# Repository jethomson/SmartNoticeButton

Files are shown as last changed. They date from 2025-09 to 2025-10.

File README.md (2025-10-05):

### Introduction
An ESP32 based event scheduler that gives visual and aural notices using LEDs, mp3s saved in flash, and a free TTS service. The case is a big, 3d printed button with a clear cap to show the LEDs. 

<video src="https://private-user-images.githubusercontent.com/2336438/492090742-1041dd4a-3f88-4e7f-9b9a-afa4a4d0a438.mp4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" controls></video>

picture of the web UI for creating events

### Programming ESP32
There are two different ways you can load the code and example files onto the ESP32.

**Method 1**
<br>
[Use a browser that supports Web Serial and program the ESP32 board with this page.](
https://jethomson.github.io/SmartNoticeButton/webflash/flash.html)

**Method 2**
<br>
Download this repository and open it in PlatformIO.
Compile and upload the code.
Click the ant icon on the left hand side, under Platform, click Build Filesystem Image, then click Upload Filesystem Image.

### Hardware
[ESP32 D1 Mini - USB C - Aliexpress](https://www.aliexpress.us/item/3256805791099168.html)
<br>
[ESP32 D1 Mini - USB C - Amazon](https://www.amazon.com/AITRIP-ESP-WROOM-32-Bluetooth-Internet-Development/dp/B0CYC227YG)
<br>
[FCOB LED strip - 5 mm width - Amazon](https://www.amazon.com/dp/B0DBZPL55D)
<br>
[Common WS2812B LED strip - Amazon](https://www.amazon.com/SEZO-Individually-Addressable-Programmable-Non-Waterproof/dp/B097BWJGYK)
<br>
[Max98357 I2S 3W Class D Amplifier - Amazon](https://www.amazon.com/dp/B0B4GK5R1R)
<br>
Normally open momemtary push button with a tall, 6 mm plunger
<br>
Speaker - salvaged from an old desktop (an additional print file of the base without a speaker hole is included so you can add a hole that fits your speaker)
<br>
Three sticky rubber feet for the bottom (not required, but the sound will escape better)

ESP32 to LED strip wiring:
<br>
IO16 -- Green -- DIN 
<br>
 GND -- White -- GND  (use the GND next to IO0)
<br>
 VCC --  Red  --  5V  (use VCC next to IO2)
<br>

ESP32 to Max98357 board wiring:
<br>
IO22 -- Orange -- LRC (wclkPin) 
<br>
IO21 -- Yellow -- BCLK (bclkPin) 
<br>
IO17 -- Green -- DIN (doutPin) 
<br>
 VCC --  Red --  Vin
<br>
 GND -- Black  -- GND
<br>

ESP32 to push button wiring:
<br>
IO26 -- Green -- SW_IN 
<br>
 GND -- Black -- SW_OUT (use the GND next to TXD)

Max98357 board to speaker wiring:
<br>
\+ (plus) hole -- Green -- \+ (plus) pad
<br>
\- (minus) hole -- White -- \- (minus) pad
<br>

photo of smart button disassembled

<br>
Large button cap and plunger hat are printed in a clear PLA.
<br>
Push button support and diffuser are printed in white PLA.
<br>
The base and retaining ring are printed in black PLA.
<br>
<br>
The button cap and diffuser were printed using the following settings in Orca Slicer:
<br>
&nbsp;&nbsp;Quality
<br>
&nbsp;&nbsp;&nbsp;&nbsp;Seam position: Random
<br>
&nbsp;&nbsp;Strength
<br>
&nbsp;&nbsp;&nbsp;&nbsp;Top surface pattern: Archimedean Chords
<br>
&nbsp;&nbsp;&nbsp;&nbsp;Bottom surface pattern: Archimedean Chords
<br>
&nbsp;&nbsp;&nbsp;&nbsp;Sparse infill pattern: Archimedean Chords
<br>
&nbsp;&nbsp;&nbsp;&nbsp;Internal solid infill pattern: Archimedean Chords
<br>
&nbsp;&nbsp;Others
<br>
&nbsp;&nbsp;&nbsp;&nbsp;Reduce infill retraction: unchecked
<br>
Reduce infill retraction prevents stray bits of filament being visible in the infill since the filament is clear.
<br>
A layer height of 0.12 mm was used for the button and 0.2 mm was used for the diffuser.
<br>
<br>
I do not recommend printing the retaining rink with Archimedean Chords. I had trouble with a ring printed this way leaving gaps.
<br>

### Initial Setup
The device can create its own WiFi network or it can connect to your established WiFi network.
You can control the device by connecting directly to its WiFi network, but you will be able to access the device more easily and be able to use the time and date features if you connect it to your WiFi network.

Find the WiFi network named SmartButton and connect to it.
You may get a dialog message like: "The network has no internet access. Stay connected?"
If so, answer Yes. I do not recommend marking the box "[ ] Don't ask again for this network"
In a web browser, open the site smartbutton.local or 192.168.4.1.
Open the Configuration page.
Enter your WiFi network information (SSID and password).
The rest of the fields may be ignored for now.
Click Save.
The device should restart and connect to your WiFi network.
The SmartButton WiFi network should no longer be visible in your list of available networks.
It will appear again if the device no longer has access to your WiFi network (e.g. password changed).

Now any computer or phone on your WiFi network will be able to control the device be visiting smartbutton.local.

**LEDs config**

LEDs number is the count of LEDs in your strip.

LEDs offset is the LED index you want to treat as if it was the start of your LED strip. Since there are physical limitations on where the actual start of the strip can be, the software lets you shift the apparent location of LED 0 to make the visual patterns have a more pleasing orientation.

**VoiceRSS API Key**

[Voice RSS](https://voicerss.org/) offers a free API key for their TTS service with a limit of 350 requests per day. The sign up process is simple and only requires an email address.

**Setting the timezone**

If you want to use UTC time then nothing further is required.

If you would like to use your local time:
<br>
Go to smartbutton.local again and open the Configuration page.
<br>
Delete the information in the IANA Timezone field, and click outside of that field.
With luck your IANA Timezone will be filled in automatically based on the location of your IP address, then a few moments later the POSIX Timezone (has Daylight Saving Time info) will also automatically be filled in. If this information is not correct you can manually set the IANA Timezone, then the POSIX Timezone will automatically update.
Click Save and wait for the device to restart.
Now you should be able to add the time and date to your composites.

### Sound Files and Licences

[chime01.mp3 :: what-friends-are-for-507.mp3](https://notificationsounds.com/wake-up-tones/what-friends-are-for-507)&nbsp;&nbsp;&nbsp;&nbsp;[Creative Commons Attribution license](https://creativecommons.org/licenses/by/4.0/legalcode)<br>
[chime02.mp3 :: simple-notification-1520254.mp3 by Universfield](https://pixabay.com/sound-effects/simple-notification-152054/)&nbsp;&nbsp;&nbsp;&nbsp;[Pixabay license](https://pixabay.com/service/license-summary/)<br>
[chime03.mp3 :: Tannoy chime 01.mp3 by kwahmah_02](https://freesound.org/people/kwahmah_02/sounds/245954/)&nbsp;&nbsp;&nbsp;&nbsp;[Creative Commons Attribution license](https://creativecommons.org/licenses/by/3.0/)<br>

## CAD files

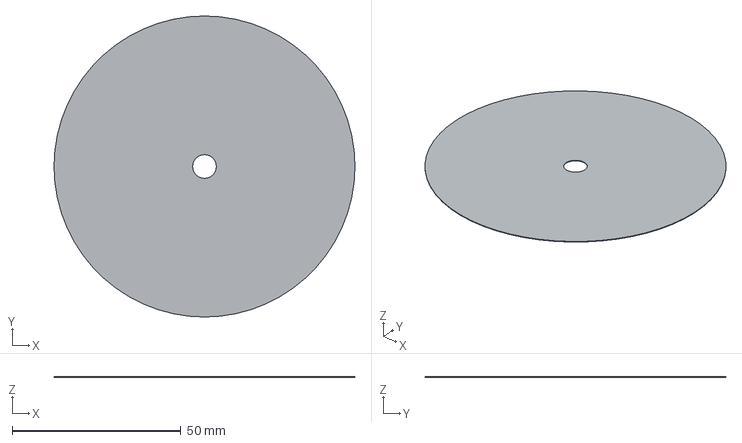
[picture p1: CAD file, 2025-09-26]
3d_printer_files/diffuser.step
89.2 x 89.2 x 0.2 mm

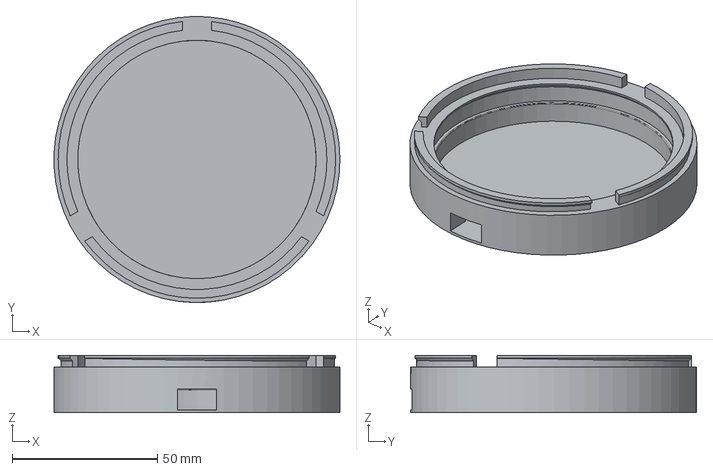
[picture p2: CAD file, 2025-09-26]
3d_printer_files/base_no_speaker_hole.step
98.4 x 98.4 x 19.8 mm

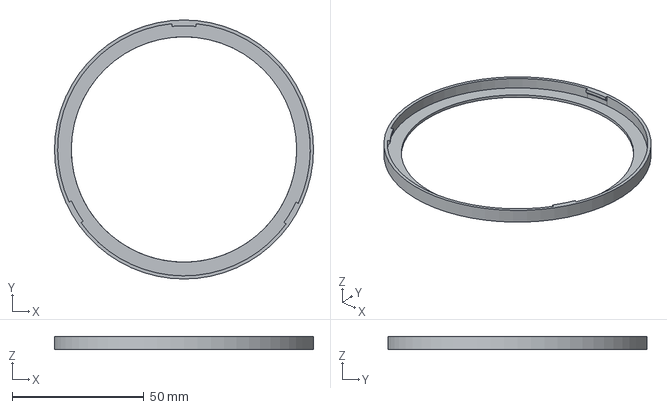
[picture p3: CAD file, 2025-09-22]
3d_printer_files/ring.step
98.4 x 98.4 x 5.00 mm

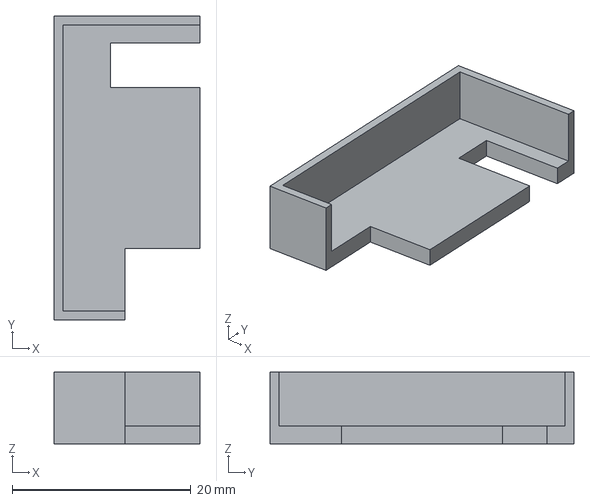
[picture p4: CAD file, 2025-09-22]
3d_printer_files/pushbutton_support.step
16.3 x 34.0 x 8.00 mm

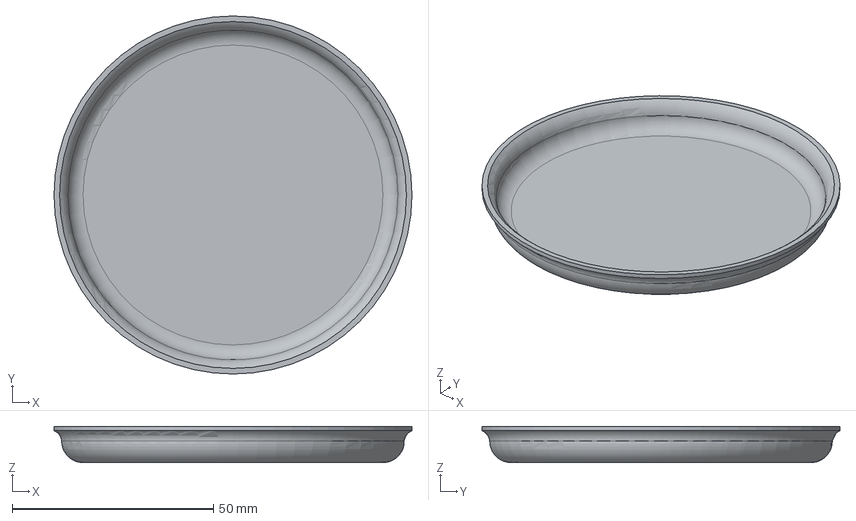
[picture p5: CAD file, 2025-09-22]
3d_printer_files/button_cap.step
89.0 x 89.0 x 9.00 mm

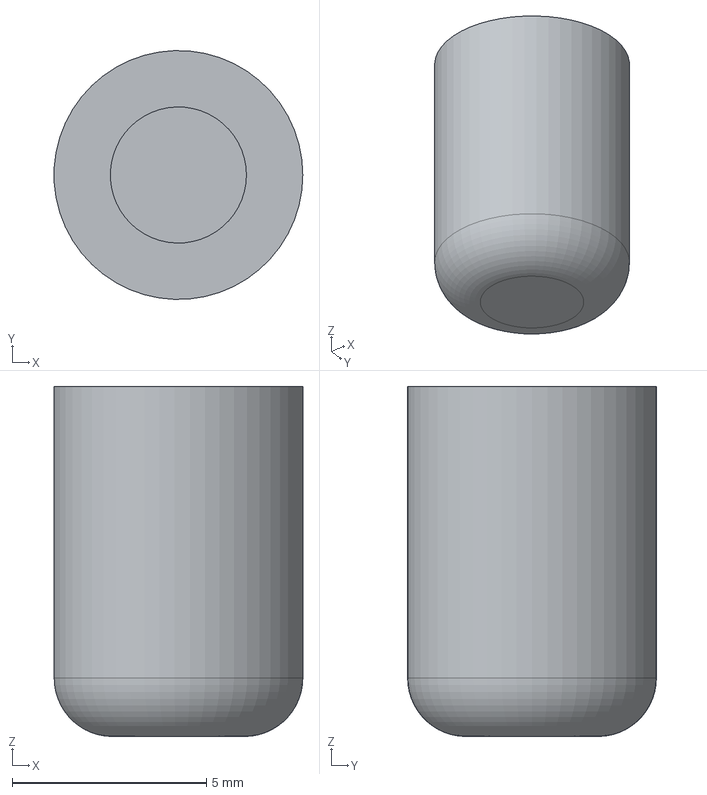
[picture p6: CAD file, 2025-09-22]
3d_printer_files/plunger_hat.step
6.39 x 6.40 x 9.00 mm

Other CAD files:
3d_printer_files/base.step
3d_printer_files/base.stl
3d_printer_files/base_no_speaker_hole.stl
3d_printer_files/button_cap.stl
3d_printer_files/diffuser.stl
3d_printer_files/plunger_hat.stl
3d_printer_files/pushbutton_support.stl
3d_printer_files/ring.stl

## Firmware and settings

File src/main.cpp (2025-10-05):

// events.json specification
// d == description (max 100 chars), f == frequency, sd == start date, st == start time, ed == end date, et == end time, e == exclude, p == pattern, c == color, s == sound, v == voice
// frequency: d == Daily, w == weekly, m == Monthly, y == Yearly
// exclude: is an 8 bit number that stores the sum of the days of the week you wish to skip
//          1 for Sunday, 2 for Monday, 4 for Tuesday, 8 for Wednesday, 16 for Thursday, 32 for Friday, 64 for Saturday
//          for example, if you wish to exclude Saturday and Sunday, then set exclude to 1 + 64 => e:65
//
//{"events":[
//           {"d":"Feed+Fish%2C+Morning","f":"d","sd":[2024,9,25],"st":[8,0,0],"ed":null,"et":null,"e":65,"p":2,"c":"0x00FF0000","s":"chime.mp3","v":"en-ca&v=Clara"},
//           {"d":"Feed+Fish%2C+Afternoon","f":"d","sd":[2024,9,25],"st":[16,0,0],"ed":null,"et":null,"e":65,"p":0,"c":"0x000000FF","s":"chime.mp3","v":"en-ca&v=Clara"}
//          ]
//}
//
// descriptions are percent encoded by the frontend and stored in this format so they can be easily passed to the TTS API.
// the backend trusts that the frontend gives it valid, preformatted data.
// generally, not the best idea, but this is just a personal project and not implement formatting like percent encoding in the backend simplifies the code.


#include <Arduino.h>
#include <FS.h>
//#include "credentials.h" // set const char *wifi_ssid and const char *wifi_password in include/credentials.h
#include <WiFi.h>
#include <WiFiUdp.h>
#include <ESPAsyncWebServer.h>
#include <DNSServer.h>
#include <ESPmDNS.h>
#include <LittleFS.h>
#include <Preferences.h>

#include <FastLED.h>

#include "ArduinoJson-v6.h"
#include <StreamUtils.h>

#include "Button2.h"

#include "AudioFileSourceHTTPStream.h"
#include "AudioFileSourceSPIFFS.h"
#include "AudioFileSourceBuffer.h"
#include "AudioGeneratorMP3.h"
#include "AudioOutputI2S.h"

#include "driver/i2s.h"

#include <vector>

// storage locations for animated matrices and playlists.
// note the pathes are hardcoded in the HTML files, so changing these defines is not enough.
// do not put a / at the end
#define FILE_ROOT "/files"
#define SND_ROOT FILE_ROOT "/snd"
#define USR_ROOT FILE_ROOT "/usr"

#define WIFI_CONNECT_TIMEOUT 10000 // milliseconds
#define SOFT_AP_SSID "SmartButton"
#define MDNS_HOSTNAME "smartbutton"

#define DATA_PIN 16
#define COLOR_ORDER GRB
#define LED_STRIP_VOLTAGE 5
#define LED_STRIP_MILLIAMPS 270
#define HOMOGENIZE_BRIGHTNESS true

#define BUTTON_PIN 26 

#define EVENT_CHECK_INTERVAL 5000 // milliseconds. how frequently checks for events happening now should occur.

#define DESCRIPTION_SIZE 301 // frontend allows up to 100 but with percent encoding the description could become much longer.
#define SOUND_SIZE 101
#define VOICE_SIZE 15 // longest voice string for voicerss: fr-ca&v=Olivia

#define RANDOM_SOUND_MARKER "?????"
#define HTTP_SOUND_PREFIX "http://"

#define SENTINEL_EVENT_ID -1 // event.id is always non-negative, so -1 indicates never seen

#undef DEBUG_CONSOLE
#define DEBUG_CONSOLE Serial
#if defined DEBUG_CONSOLE && !defined DEBUG_PRINTLN
  #define DEBUG_BEGIN(x)     DEBUG_CONSOLE.begin (x)
  #define DEBUG_PRINT(x)     DEBUG_CONSOLE.print (x)
  #define DEBUG_PRINTDEC(x)     DEBUG_PRINT (x, DEC)
  #define DEBUG_PRINTLN(x)  DEBUG_CONSOLE.println (x)
  #define DEBUG_PRINTF(...) DEBUG_CONSOLE.printf(__VA_ARGS__)
  #define DEBUG_FLUSH()     DEBUG_CONSOLE.flush ()
#else
  #define DEBUG_BEGIN(x)
  #define DEBUG_PRINT(x)
  #define DEBUG_PRINTDEC(x)
  #define DEBUG_PRINTLN(x)
  #define DEBUG_PRINTF(...)
  #define DEBUG_FLUSH()
#endif

struct Timezone {
  // TZ is only set at boot, so it is possible for iana_tz and posix_tz to have been updated from default values, but not put into effect yet.
  // therefore we use a separate variable to track if the default timezone is in use instead of trying to do something like compare iana_tz or posix_tz to "" (empty string)
  bool is_default_tz;
  String iana_tz;
  // input from frontend, passed to timezoned.rop.nl for verification and fetching corresponding posix_tz
  // a separate varible is used instead of iana_tz to prevent losing previous data if verify_timezone() fails for some reason (e.g. unverified_iana_tz is an invalid timezone).
  String unverified_iana_tz; 
  String posix_tz;
} tz;

Preferences preferences;

AsyncWebServer web_server(80);
DNSServer dnsServer;
IPAddress IP;
String mdns_host;
bool dns_up = false;

bool restart_needed = false;

// any changes to LEDS_ORIGIN_OFFSET here will be overwritten.
// LEDS_ORIGIN_OFFSET is set in the frontend.
// and DEFAULT_LEDS_ORIGIN_OFFSET is set in platformio.ini.
// since you may be physically limited where you place the first LED when assembling the button
// LEDS_ORIGIN_OFFSET lets you adjust where the apparent origin is. for example, if the first
// LED is physically wired at 1 o'clock you change LEDS_ORIGIN_OFFSET to a value different from
// 0 such that origin *appears* as if it is at 6 o'clock.
uint16_t LEDS_ORIGIN_OFFSET = 0;
// any changes to NUM_LEDS here will be overwritten.
// NUM_LEDS is set in the frontend.
// and DEFAULT_NUM_LEDS is set in platformio.ini.
uint16_t NUM_LEDS = 0;
CRGB* leds;
uint8_t homogenized_brightness = 255;

bool is_audio_message_queued = false;
Button2 button;

struct Event {
  uint16_t id;
  struct tm datetime;
  char frequency;
  struct tm end_datetime;
  char description[DESCRIPTION_SIZE];
  uint8_t exclude;
  uint8_t pattern;
  uint32_t color;
  char sound[SOUND_SIZE];
  bool is_random_sound;
  char voice[VOICE_SIZE];
  time_t timestamp;
};

std::vector<Event> events;
bool events_reload_needed = false;

struct AudioMessage {
  uint32_t id;
  char description[DESCRIPTION_SIZE];
  char sound[SOUND_SIZE];
  char voice[VOICE_SIZE];
  time_t timestamp;
  bool do_long_notify;
};

QueueHandle_t qaudio_messages = xQueueCreate(25, sizeof(struct AudioMessage));

enum Pattern {
  SOLID = 0,
  BREATHE = 1,
  BLINK = 2,
  SPIN = 3,
  TWINKLE = 4
};

enum SpecialColor {
  RAINBOW     = 0x01000000,
  RED_GREEN   = 0x01000001,
  ORANGE_BLUE = 0x01000002,
  YELLOW_PURPLE = 0x01000003
};

std::vector<uint8_t> patterns;
std::vector<uint8_t> special_colors;

uint8_t num_special_colors = 0;

const char* stored_file_list = FILE_ROOT "/file_list.json";
//const char* sound_URLs = FILE_USR "/sound_URLs.json";

String patterns_json;
String special_colors_json;

bool is_wait_over(uint16_t interval);
bool finished_waiting(uint16_t interval);
void homogenize_brightness(void);
void show(void);

void breathing(uint16_t draw_interval);
void blink(uint16_t draw_interval, uint8_t num_blinks, uint8_t num_intervals_off);
//uint16_t forwards(uint16_t index_in);
uint16_t backwards(uint16_t index_in);
void spin(uint16_t draw_interval, uint16_t(*dfp)(uint16_t));
void twinkle(uint16_t draw_interval);
void fill_gradient_RGB_circular(CRGB* leds, CRGB start_color, CRGB end_color);
void fill(uint32_t color);
void visual_reset(void);
void visual_notifier(void);

//void status_callback(void *cbData, int code, const char *string);
void play(AudioFileSource* file);
bool is_valid_mp3_URL(const char* url);
void http_sound(const char* url);
void tell(const char* description, const char* voice, time_t timestamp, bool do_long_notify);
void file_sound(String filename);
void aural_notifier(void* parameter);

bool create_patterns_list(void);
bool create_special_colors_list(void);

void fill_in_datetime(tm* datetime);
tm new_time(uint32_t value, char unit);
tm refresh_datetime(tm datetime, char frequency);
bool is_expired(tm datetime, tm end_datetime);
uint16_t new_id(void);
void set_random_sound(char* sound, size_t sound_len);
bool load_events_file(void);
bool save_file(String fs_path, String json, String& message);
void check_for_recent_events(uint16_t interval);

void single_click_handler(Button2& b);
void long_click_handler(Button2& b);

bool verify_timezone(const String iana_tz);
void espDelay(uint32_t ms);
bool attempt_connect(void);
String get_ip(void);
String get_mdns_addr(void);
//String processor(const String& var);
void wifi_AP(void);
bool wifi_connect(void);
void mdns_setup(void);
bool filterOnNotLocal(AsyncWebServerRequest *request);
void web_server_station_setup(void);
void web_server_ap_setup(void);
void web_server_initiate(void);
time_t time_provider();



// If two functions running close to each other both call is_wait_over()
// the one with the shorter interval will reset the timer such that the
// function with the longer interval will never see its interval has
// elapsed, therefore a second function that does the same thing as
// is_wait_over() has been added. This is only a concern when a pattern
// function and an overlay function are both called at the same time.
// Patterns should use is_wait_over() and overlays should use finished_waiting(). 
bool is_wait_over(uint16_t interval) {
    static uint32_t pm = 0; // previous millis
    if ( (millis() - pm) > interval ) {
        pm = millis();
        return true;
    }
    else {
        return false;
    }
}


bool finished_waiting(uint16_t interval) {
    static uint32_t pm = 0; // previous millis
    if ( (millis() - pm) > interval ) {
        pm = millis();
        return true;
    }
    else {
        return false;
    }
}


// When FastLED's power management functions are used FastLED dynamically adjusts the brightness level to be as high as possible while
// keeping the power draw near the specified level. This can lead to the brightness level of an animation noticeably increasing when
// fewer LEDs are lit and the brightness noticeably dipping when more LEDs are lit or their colors change.
// homogenize_brightness() learns the lowest brightness level of all the animations and uses it across every animation to keep a consistent
// brightness level. This will lead to dimmer animations and power usage almost always a good bit lower than what the FastLED power
// management function was set to aim for. Set the #define for HOMOGENIZE_BRIGHTNESS to false to disable this feature.
void homogenize_brightness(void) {
    uint8_t max_brightness = calculate_max_brightness_for_power_vmA(leds, NUM_LEDS, homogenized_brightness, LED_STRIP_VOLTAGE, LED_STRIP_MILLIAMPS);
    if (max_brightness < homogenized_brightness) {
        homogenized_brightness = max_brightness;
    }
}


void show(void) {
  homogenize_brightness();
  //FastLED.setBrightness(homogenized_brightness);
  FastLED.show();
}


uint16_t idx(uint16_t index_in) {
  return (LEDS_ORIGIN_OFFSET + index_in) % NUM_LEDS;
}


uint8_t br_delta = 0;
void breathing(uint16_t draw_interval) {
  const uint8_t min_brightness = 2;
  if (finished_waiting(draw_interval)) {
    // since FastLED is managing the maximum power delivered use the following function to find the _actual_ maximum brightness allowed for
    // these power consumption settings. setting brightness to a value higher that max_brightness will not actually increase the brightness.
    uint8_t max_brightness = calculate_max_brightness_for_power_vmA(leds, NUM_LEDS, homogenized_brightness, LED_STRIP_VOLTAGE, LED_STRIP_MILLIAMPS);
    uint8_t b = scale8(triwave8(br_delta), max_brightness-min_brightness)+min_brightness;

    FastLED.setBrightness(b);

    br_delta++;
  }
}


uint8_t bl_count = 0;
void blink(uint16_t draw_interval, uint8_t num_blinks, uint8_t num_intervals_off) {
  if (finished_waiting(draw_interval)) {
    if (bl_count < (2*num_blinks)) {
      uint8_t b = (bl_count % 2 == 0) ? homogenized_brightness : 0;
      FastLED.setBrightness(b);
    }
    bl_count++;
    if (bl_count >= 2*num_blinks + num_intervals_off-1) {
      bl_count = 0;
    }
  }
}
 

//uint16_t forwards(uint16_t index_in) {
//  return index_in;
//}


uint16_t backwards(uint16_t index_in) {
  return idx((NUM_LEDS-1)-index_in);
}


void spin(uint16_t draw_interval, uint16_t(*dfp)(uint16_t)) {
  if (finished_waiting(draw_interval)) {
    CRGB color0 = leds[(*dfp)(idx(NUM_LEDS-1))];
    for(uint16_t i = NUM_LEDS-1; i > 0; i--) {
      leds[(*dfp)(idx(i))] = leds[(*dfp)(idx(i-1))];
    }
    leds[(*dfp)(idx(0))] = color0;
  }
}


void twinkle(uint16_t draw_interval) {
  if (finished_waiting(draw_interval)) {
    for(uint16_t i = 0; i < NUM_LEDS; i++) {
      if (random8() < 16) {
        // no real reason to use idx() since these are random indices
        leds[i] = CRGB::White - leds[i];
      }
    }
  }
}


void fill_gradient_RGB_circular(CRGB* leds, CRGB start_color, CRGB end_color) {
  CRGBPalette16 palette;
  for (uint8_t i = 0; i < 16; i++) {
      float ratio = i / 15.0;
      palette[i] = blend(start_color, end_color, ratio*255);
  }
  for (uint16_t i = 0; i < NUM_LEDS; i++) {
    leds[idx(i)] = ColorFromPalette(palette, (i*255)/NUM_LEDS);
  }
}


void fill(uint32_t color) {
  // regular RGB color only uses 24 bits but if color is stored in 32 bits
  // we can utilize the unused upper bits to indicate a color is special
  // colors less than or equal to 0x00FFFFFF are normal RGB colors
  uint8_t color_flag = (color >> 24);
  if (color_flag == 0x00) {
    fill_solid(leds, NUM_LEDS, color);
  }
  else if (color_flag == 0x01) {
    // 0x01------ flag indicates special colors
    if (static_cast<SpecialColor>(color) == RAINBOW) {
      // cannot manipulate the LED indices with idx() for fill_rainbow_circular, but can change the hue at leds[0] which
      // accomplishes the same goal of changing the apparent origin of the LEDs
      const uint16_t hueChange = 65535 / (uint16_t) NUM_LEDS;  // hue change for each LED, * 256 for precision (256 * 256 - 1)
      uint16_t initialhue = (uint8_t)((LEDS_ORIGIN_OFFSET*hueChange) >> 8);  // assign new hue with precise offset (as 8-bit)
      fill_rainbow_circular(leds, NUM_LEDS, initialhue);
    }
    else {
      CRGB color1 = CRGB::Black;
      CRGB color2 = CRGB::Pink;
      if (color == RED_GREEN) {
        color1 = CRGB::Red;
        color2 = CRGB::Green;
      }
      else if (color == ORANGE_BLUE) {
        color1 = CRGB::Orange;
        color2 = CRGB::Blue;
      }
      else if (color == YELLOW_PURPLE) {
        color1 = CRGB::Yellow;
        color2 = CRGB::Purple;
      }
      //fill_gradient_RGB() shows colors more distinctly than fill_gradient()
      //half and half looks better than a gradient since the button cover already diffuses the color
      uint8_t i = 0;
      while(i < NUM_LEDS/2) {
        leds[idx(i)] = color1;
        i++;
      }
      while(i < NUM_LEDS) {
        leds[idx(i)] = color2;
        i++;
      }
    }
  }
  else if (color_flag == 0x02) {
    // 0x02------ flag indicates to fade color across gradient fill
    color = color & 0x00FFFFFF;
    CRGB color_dim = color;
    color_dim.nscale8(20); // lower numbers are closer to black
    fill_gradient_RGB_circular(leds, color, color_dim);
  }
  else {
    // black and pink is used to indicate something went wrong during testing
    fill_gradient_RGB_circular(leds, CRGB::Black, CRGB::Pink);
  }
}


void visual_reset(void) {
  br_delta = 0;
  bl_count = 0;
  finished_waiting(0); // effectively resets timer used for visual effects
  FastLED.clear();
}


// last_id_seen needs to be global so it can be set back to the default by long_click_handler()
// otherwise a reoccurrence of an event with the same id as last_id_seen may not be shown.
int32_t last_id_seen = SENTINEL_EVENT_ID; // event.id is always non-negative, so last_id_seen of -1 indicates never seen
void visual_notifier(void) {
  // NOTE:
  // a design decision was made that the color used by a pattern will not evolve over time.
  // shifting colors are visually appealing, but they are counter productive to serving as a visual indicator
  // for example: one event is blinking blue, and another event is blinking with a shifting color
  //              the shifting color will eventually show blue, so you would have two separate events showing
  //              the same visual indicator.
  const uint32_t SHOW_TIME = 4000; // milliseconds
  static uint16_t i = 0;
  static uint32_t pm = 0;
  static bool refill = true;
  if (!events.empty()) {
    if (i >= events.size()) {
      // if an event was deleted i might be greater than the number of events, so reset it.
      i = 0;
    }
    struct Event event = events[i];
    if (event.timestamp != 0) {
      // if timestamp is 0 then event has not happened since last time notices were cleared
      // so there is no need to show a visual notice for it

      if (event.id != last_id_seen) {
        // by tracking the last_id_seen we can determine if a new notice is about to be shown
        // if it is new notice then reinitialize
        // should only reinitialize once for the SHOW_TIME interval so the pattern can be
        // animated correctly instead of being restarted over and over
        last_id_seen = event.id;
        refill = true;
        visual_reset();
      }

      uint8_t pattern = event.pattern;
      uint8_t randomness = (uint8_t)event.timestamp;
      if (pattern == 255) {
        // 255 indicates a random pattern should be used
        pattern = randomness % patterns.size();
      }
      uint32_t color = event.color;
      if (color == 0xFFFFFFFF) {
        // 0xFFFFFFFF indicates a random color should be used
        bool do_basic = randomness % 3;

        if (do_basic) {
          color = (uint32_t)(CRGB)CHSV((randomness % 255), 255, 255);
          color &= 0x00FFFFFF; // make sure the upper bits are zero to indicate a basic color
        }
        else {
          // do special color
          color = 0x01000000 + (randomness % special_colors.size());
        }
      }

      // for DEBUGGING
      //if (refill) {
      //  DEBUG_PRINT("description: ");
      //  DEBUG_PRINTLN(event.description);
      //  DEBUG_PRINT("pattern: ");
      //  DEBUG_PRINTLN(pattern);

      //  DEBUG_PRINT("color: ");
      //  char hex_color[11];
      //  snprintf(hex_color, sizeof(hex_color), "0x%08lX", color);
      //  DEBUG_PRINTLN(hex_color);
      //}

      switch (pattern) {
        case SOLID:
          FastLED.setBrightness(homogenized_brightness);
          if (refill) {
            refill = false;
            fill(color);
          }
          break;
        case BREATHE:
          if (refill) {
            refill = false;
            fill(color);
          }
          breathing(10);
          break;
        case BLINK:
          //FastLED.setBrightness(homogenized_brightness); // do not use this here. blink changes brightness.
          if (refill) {
            refill = false;
            fill(color);
          }
          blink(200, 3, 10);
          break;
        case SPIN:
          FastLED.setBrightness(homogenized_brightness);
          if (refill) {
            refill = false;
            if (color <= 0x00FFFFFF) {
              // 0x02------ flag indicates to fade color across gradient fill
              // the change in brightness across the fill makes it possible to see the spinning motion
              color += (0x02 << 24);
            }
            fill(color);
          }
          // complete rotation about every 2 seconds independent of the number of LEDs
          spin(2000/NUM_LEDS, &backwards);
          break;
        case TWINKLE:
          FastLED.setBrightness(homogenized_brightness);
          if (is_wait_over(100)) {
            // twinkles should only show momentarily
            // by refilling every time the twinkles from the previous draw disappear
            fill(color);
            twinkle(0);
          }
          break;
        default:
          break;
      }
    }

    // iterate if the event has been shown for SHOW_TIME or event should not be shown
    if ((millis()-pm) > SHOW_TIME || event.timestamp == 0) {
      pm = millis();
      i = (i+1) % events.size();
    }

    show();
  }
  // might not be a bad idea to use else{} and call visual_reset() if the events list is empty to be safe
  // but it would be called every iteration of loop() when events list is empty
}



// Called when there's a warning or error (like a buffer underflow or decode hiccup)
//void StatusCallback(void *cbData, int code, const char *string) {
//  const char *ptr = reinterpret_cast<const char *>(cbData);
//  // Note that the string may be in PROGMEM, so copy it to RAM for printf
//  char s1[64];
//  strncpy_P(s1, string, sizeof(s1));
//  s1[sizeof(s1)-1]=0;
//  DEBUG_PRINTF("STATUS(%s) '%d' = '%s'\n", ptr, code, s1);
//  DEBUG_FLUSH();
//}

//https://github.com/earlephilhower/ESP8266Audio/issues/406

//AudioOutputI2S *audio_out = new AudioOutputI2S();
AudioOutputI2S *audio_out = new AudioOutputI2S(0, 0, 32, 0); // increase DMA buffer. does this help with beginning of sound being cutoff?
AudioGeneratorMP3 *mp3 = new AudioGeneratorMP3();
bool mp3_stop_requested = false;
void play(AudioFileSource* file) {
  AudioFileSourceBuffer *buff;
  buff = new AudioFileSourceBuffer(file, 2048);
  mp3->begin(buff, audio_out);

  static int lastms = 0;
  mp3_stop_requested = false;
  while (true) {
    if (mp3 && mp3->isRunning()) {
      if (millis()-lastms > 1000) {
        lastms = millis();
        DEBUG_PRINTF("%d ms: mp3 is running...\n", lastms);
        DEBUG_FLUSH();
        vTaskDelay(pdMS_TO_TICKS(5));
      }
      if (!mp3->loop() || mp3_stop_requested) {
        mp3->stop();
        DEBUG_PRINTLN("Finished playing.");
        DEBUG_FLUSH();
        break;
      }
    }
    else {
      break;
    }
  }
  buff->close();
}
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
void loop() {
  if (dns_up) {
    dnsServer.processNextRequest();
  }

  if (restart_needed || (WiFi.getMode() == WIFI_STA && WiFi.status() != WL_CONNECTED)) {
    delay(2000);
    ESP.restart();
  }


  button.loop();
  check_for_recent_events(EVENT_CHECK_INTERVAL);
  visual_notifier();
  if (events_reload_needed) {
    events_reload_needed = load_events_file();
    FastLED.clear();
    FastLED.show();
  }

  if (tz.unverified_iana_tz != "") {
    verify_timezone(tz.unverified_iana_tz);
  }
}

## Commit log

2025-09-22 Add web pages to enable user to create events and to configure the device.
2025-09-22 Lots of improvements and bug fixes.
    [main.cpp]
2025-09-22 Lots of cleanup and fix weekly event bug.
    [main.cpp]
2025-09-22 Bug fixes: erase expired events properly, prevent audio crackle, missing visual notice because of last_id_seen
    [main.cpp]
2025-09-22 Add num LEDs config option. Fix nested optgroup bug
2025-09-22 Add 3d model files for enclosure
    [base.step, base.stl, button_cap.step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]
2025-09-22 Make changes required for web flashing
    [partitions_custom.csv]
2025-09-22 Add option to change apparent origin of LEDs to composite for physical location of LED strip start
2025-09-22 Improve formatting of datetime debugging prints
2025-09-22 Fix LED origin offset bug on config page
2025-09-22 Shrink model to better fit FCOB LEDs strip length
    [base.step, base.stl, button_cap.step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]
2025-09-25 Add fixes for html time element on mobile lacking ability to set seconds
    [main.cpp]
2025-09-26 Fix time input so it supports setting seconds on mobile devices
2025-09-26 Add base model without speaker hole so user can add own hole
    [base_no_speaker_hole.step, base_no_speaker_hole.stl]
2025-09-26 Add cut out to make room for FCOB wiring. Make diffuser hole smaller.
    [base.step, base.stl, diffuser.step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]
2025-09-27 Fix single color spin
    [main.cpp]
2025-09-30 Add ability to stop sound that is currently playing with a button press

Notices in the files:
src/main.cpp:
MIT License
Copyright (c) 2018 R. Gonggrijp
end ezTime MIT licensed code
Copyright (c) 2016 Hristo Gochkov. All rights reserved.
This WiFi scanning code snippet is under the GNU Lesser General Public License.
